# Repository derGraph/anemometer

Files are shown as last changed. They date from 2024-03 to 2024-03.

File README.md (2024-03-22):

# Ultrasonic Anemometer

This project contains the circuit and code for a ultrasonic Anemometer. The anemometer works by 4 ultrasonic Transducers where 2 of them always face each other. 2 Transducers describe one Axis, so with 4 Transducers you can measure x and y Wind components. The circuit only recieves the signal and boosts a Peak-to-Peak Sine Voltage of 50mV to a Square Wave of VCC to 0V. With the microcontroller you have to compare the time difference between the output signal, a signal of 50% Duty Cycle 40kHz and the recieved signal. Then you can calibrate your sensor with 0 wind speed. In my case i measure the Clock Cycles of an ESP8266 to get a pretty precise time.

### Circuit Description


The circuit contains of a LM324 OP-Amp and an LM393 Comperator. With these 2 IC's you can archive processing for 2 Channels. after the signal is coming from the transducer it gets biased with a VCC/2 Voltage to be in a useful working range for the later components. Then the signal is fed through a voltage follower to get a low impedance signal for the next Amplifier stage. The next stage is, as said an inverting Amplifier with a gain of 10. The gain can't be to high to have a functioning amplification. As you can see if you have signal at 40kHz the maximum gain can be 10. 
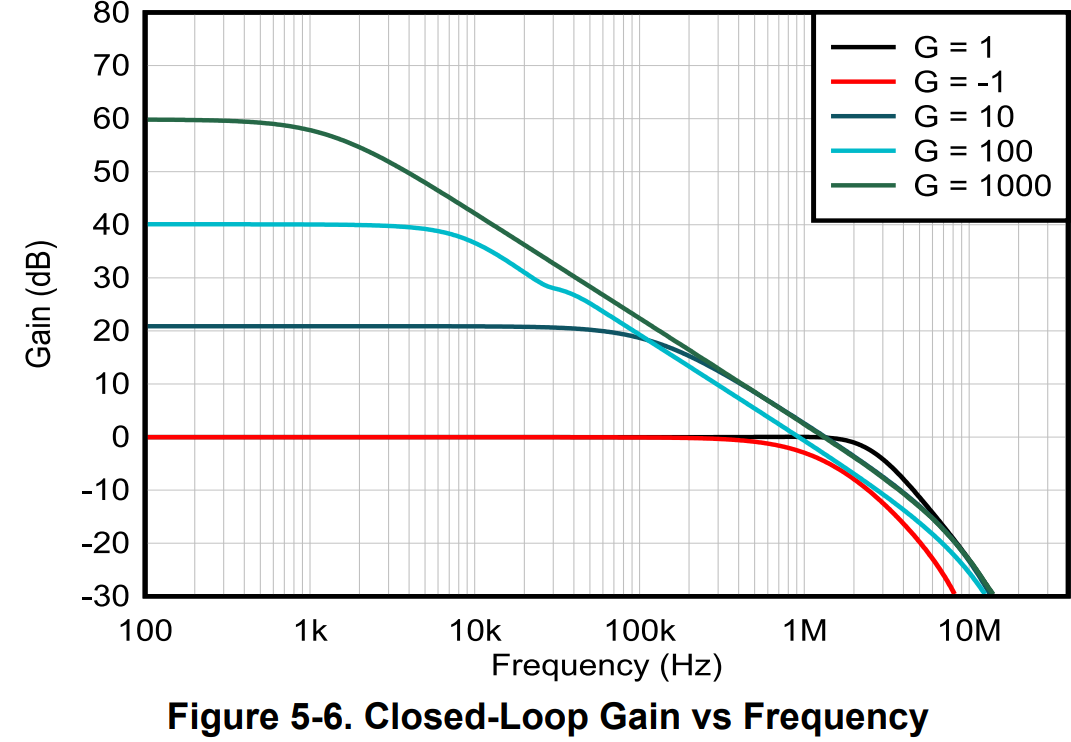
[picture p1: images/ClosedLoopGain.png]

After that the signal is fed into the LM393 Comparator. Keep in mind that to get the comperator to function you have to pull the output up. In the first revision of the board  (Rev 1) there are 2 Footprints of resistors too much (R5, R14) this is fixed with Rev 2.

### Modularity

In the standard configuration of the PCB 2 Channels are set up but if you have a weaker Signal you can cut the S2_EN between 1/2 and solder 2/3. By populating R17 and R18 you can transform your 1 Stage Amplifier in a 3 Stage Amplifier.
If you need an additional Filter you can cut EN_Filter and populate the Bandpass-Filter on the backside of the PCB.

### Full Circuit



The whole circuit contains 2 Channels with the logic to implement the 3 Stage Amplifier included in the lower one. Also there is power supply and connectors to the MCU.

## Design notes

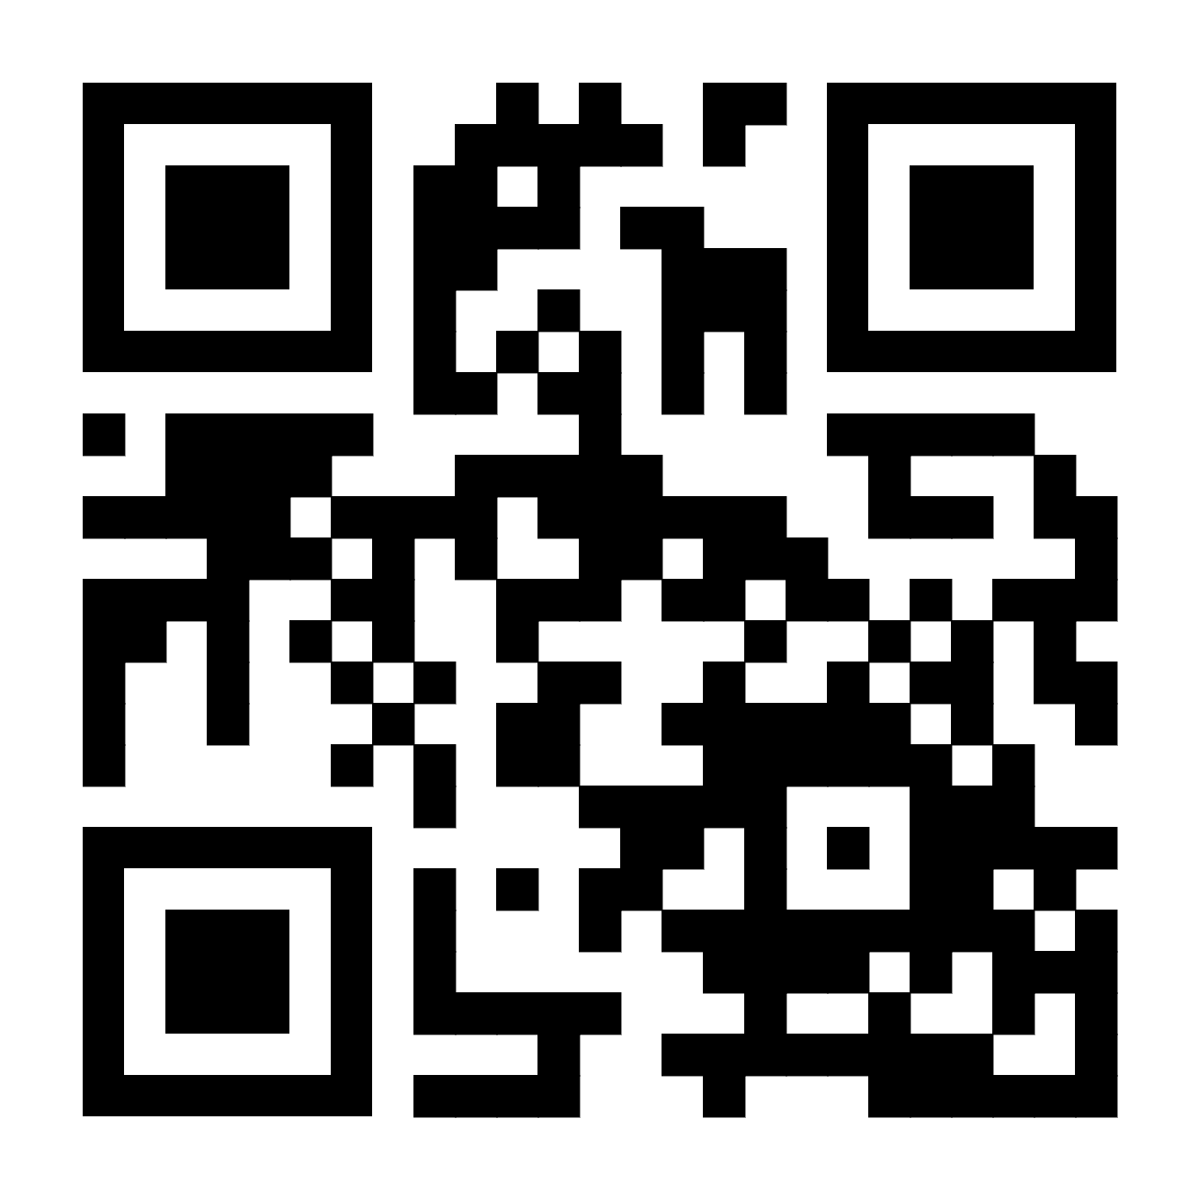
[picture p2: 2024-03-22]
KiCad/GitHubQR.png

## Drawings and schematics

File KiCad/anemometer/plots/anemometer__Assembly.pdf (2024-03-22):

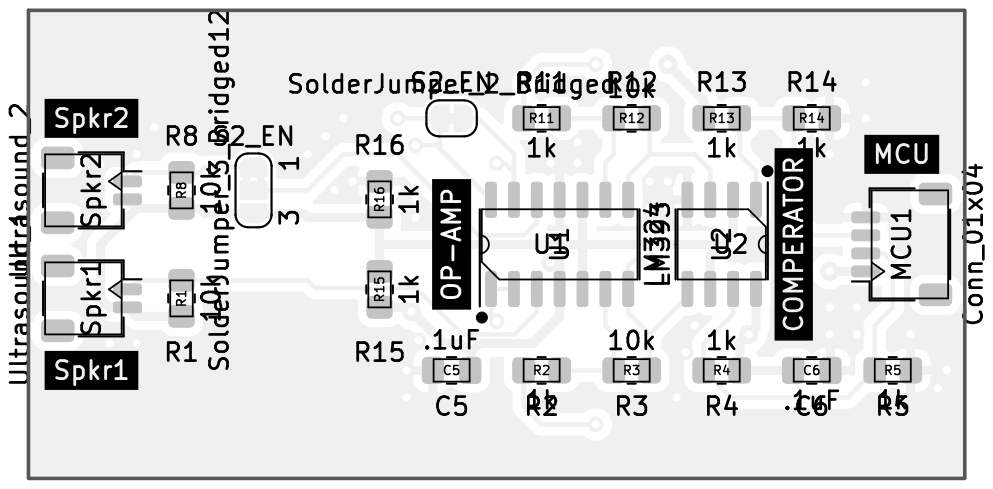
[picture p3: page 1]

Id: 1/1 Title: File: anemometer.kicad_pcb Sheet:

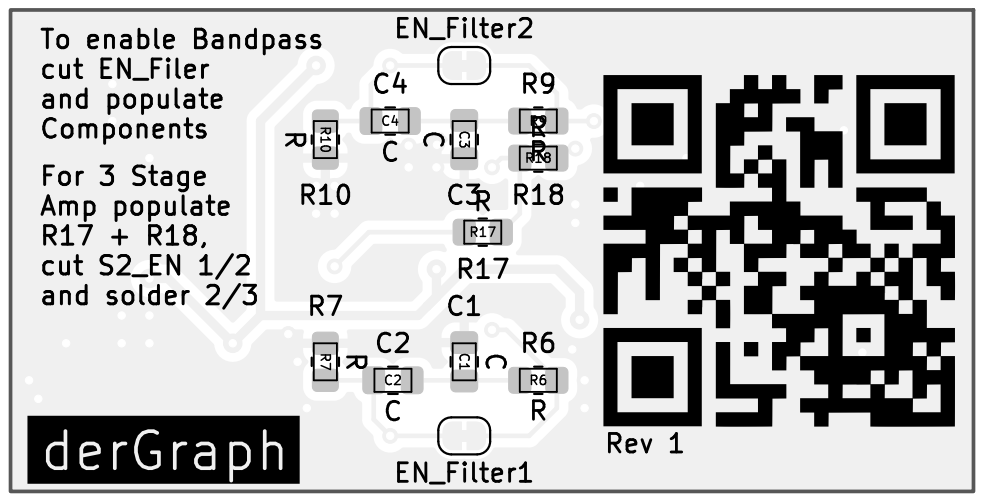
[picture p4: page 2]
D Date: KiCad; E.D.A. kicad; 7.0.5 Size: A4; Rev:; Id: 1/1 Title: File: anemometer.kicad_pcb Sheet:

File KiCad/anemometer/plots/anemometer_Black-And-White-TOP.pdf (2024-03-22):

1 | 2 | 3 | 4 | 5 | 6

A


Id: 1/1 Title: File: anemometer.kicad_pcb Sheet:

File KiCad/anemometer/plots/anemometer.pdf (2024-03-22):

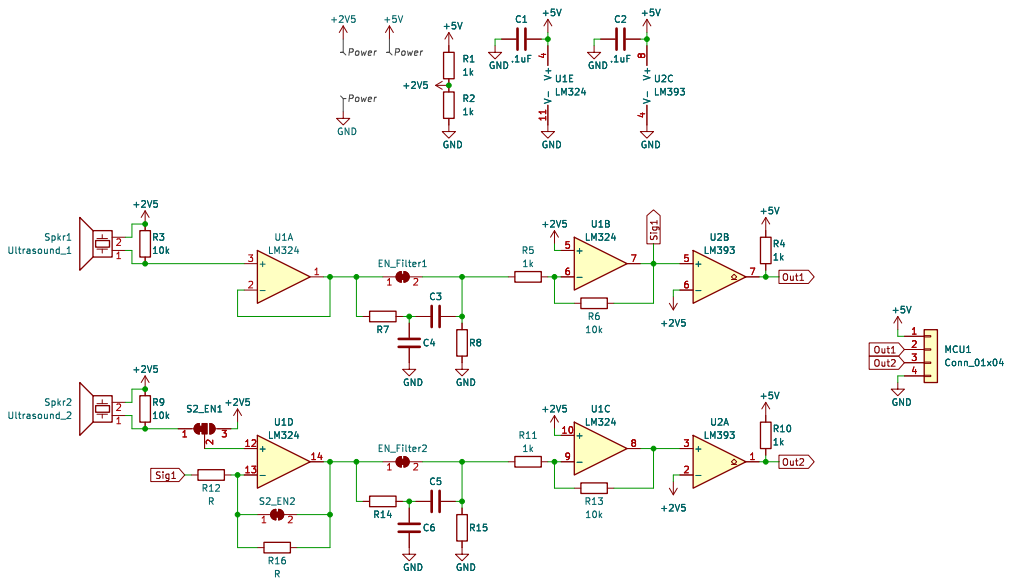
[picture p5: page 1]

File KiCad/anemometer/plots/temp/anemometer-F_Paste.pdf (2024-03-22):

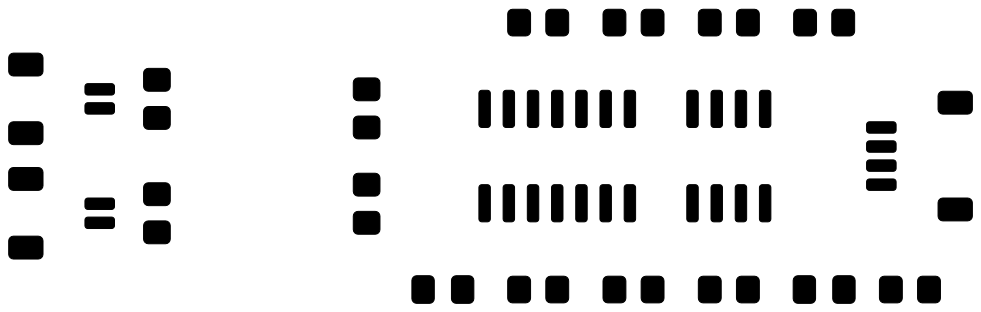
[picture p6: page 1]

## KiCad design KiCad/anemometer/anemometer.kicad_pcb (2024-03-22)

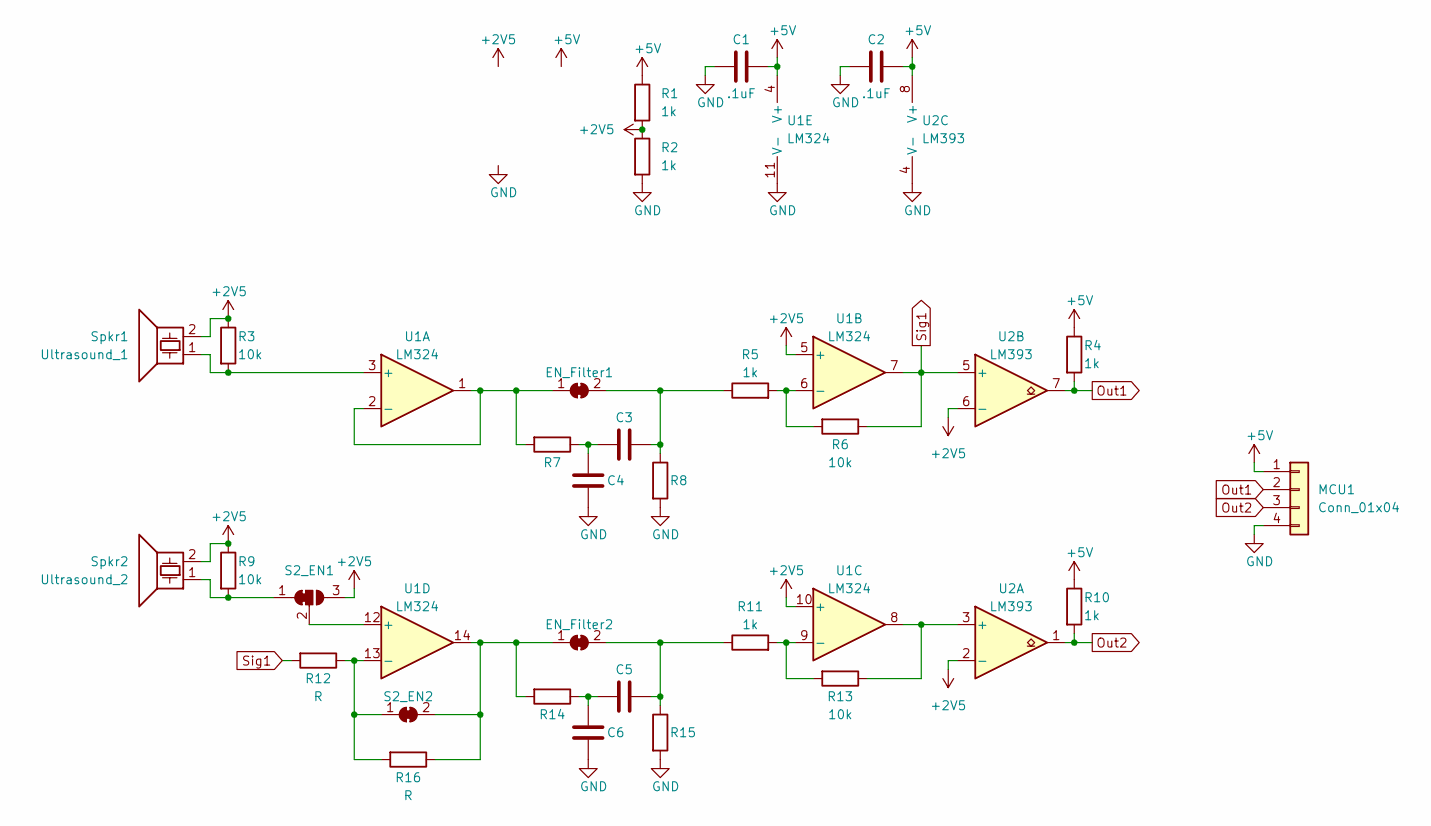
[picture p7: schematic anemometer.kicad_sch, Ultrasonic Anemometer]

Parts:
C1, C2: .1uF; C_0805_2012Metric_Pad1.18x1.45mm_HandSolder
C3, C4, C5, C6: C; C_0805_2012Metric_Pad1.18x1.45mm_HandSolder
EN_Filter1, EN_Filter2: SolderJumper_2_Bridged; SolderJumper-2_P1.3mm_Bridged_RoundedPad1.0x1.5mm
MCU1: Conn_01x04; JST_SH_SM04B-SRSS-TB_1x04-1MP_P1.00mm_Horizontal
R1, R2, R4, R5, R10, R11: 1k; R_0805_2012Metric_Pad1.20x1.40mm_HandSolder
R3, R6, R9, R13: 10k; R_0805_2012Metric_Pad1.20x1.40mm_HandSolder
R7, R8, R12, R14, R15, R16: R; R_0805_2012Metric_Pad1.20x1.40mm_HandSolder
S2_EN1: SolderJumper_3_Bridged12; SolderJumper-3_P1.3mm_Bridged2Bar12_RoundedPad1.0x1.5mm_Num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
S2_EN2: SolderJumper_2_Bridged; SolderJumper-2_P1.3mm_Bridged_RoundedPad1.0x1.5mm
Spkr1: Ultrasound_1; JST_SH_SM02B-SRSS-TB_1x02-1MP_P1.00mm_Horizontal
Spkr2: Ultrasound_2; JST_SH_SM02B-SRSS-TB_1x02-1MP_P1.00mm_Horizontal
U1: LM324; SOIC-14_3.9x8.7mm_P1.27mm
U2: LM393; SOIC-8_3.9x4.9mm_P1.27mm

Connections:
+2V5: R1.2, R2.1, R3.1, R9.1, S2_EN1.3 (B), Spkr1.2, Spkr2.2, U1.5 (+), U1.10 (+), U2.2 (-), U2.6 (-)
+5V: C1.1, C2.1, MCU1.1, R1.1, R4.1, R10.1, U1.4 (V+), U2.8 (V+)
GND: C1.2, C2.2, C4.2, C6.2, MCU1.4, R2.2, R8.2, R15.2, U1.11 (V-), U2.4 (V-)
unnamed: C3.2, C4.1, R7.1
unnamed: C5.2, C6.1, R14.1
unnamed: EN_Filter1.1 (A), R7.2, U1.1, U1.2 (-)
unnamed: C3.1, EN_Filter1.2 (B), R5.1, R8.1
unnamed: EN_Filter2.1 (A), R14.2, R16.1, S2_EN2.2 (B), U1.14
unnamed: C5.1, EN_Filter2.2 (B), R11.1, R15.1
unnamed: R9.2, S2_EN1.1 (A), Spkr2.1
unnamed: S2_EN1.2 (C), U1.12 (+)
unnamed: R12.1, R16.2, S2_EN2.1 (A), U1.13 (-)
unnamed: R3.2, Spkr1.1, U1.3 (+)
unnamed: R5.2, R6.2, U1.6 (-)
unnamed: R11.2, R13.2, U1.9 (-)
unnamed: R13.1, U1.8, U2.3 (+)
Out1: MCU1.2, R4.2, U2.7
Out2: MCU1.3, R10.2, U2.1
Sig1: R6.1, R12.2, U1.7, U2.5 (+)

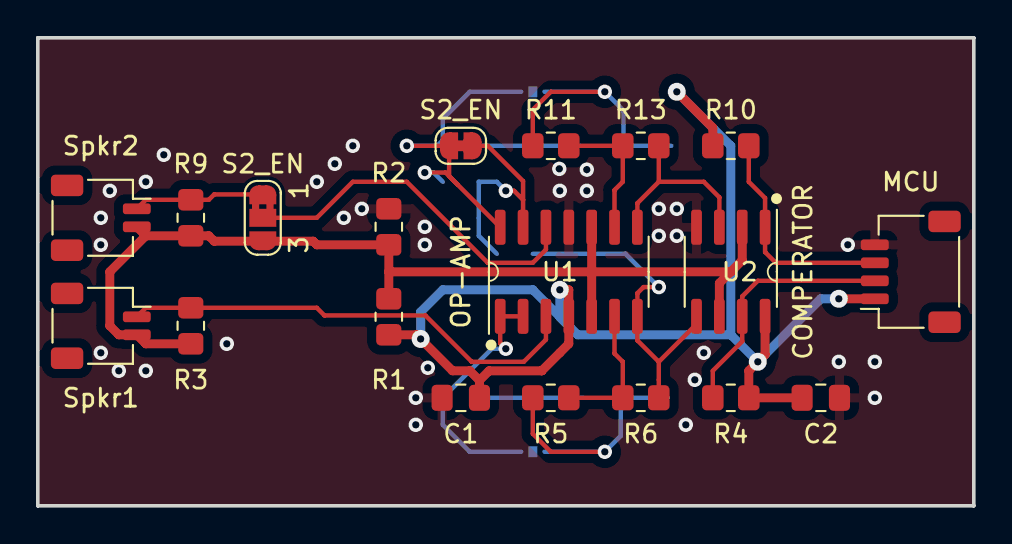
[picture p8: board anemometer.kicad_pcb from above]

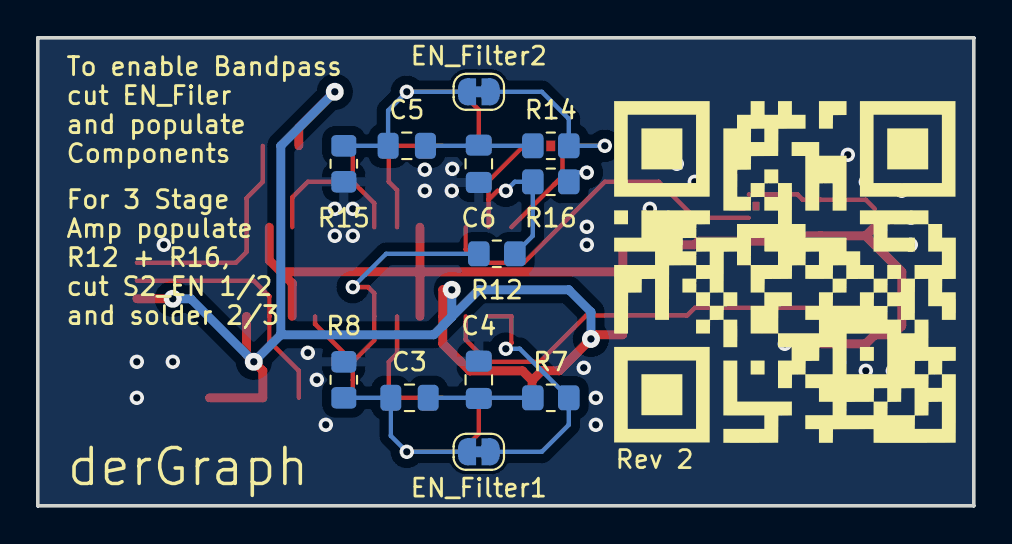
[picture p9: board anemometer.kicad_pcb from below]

Board: 2 copper layers, 52.0 x 26.0 mm, 31 parts (12 on the bottom side), 19 nets.

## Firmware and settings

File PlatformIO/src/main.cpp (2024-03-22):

#include <Arduino.h>

#define outputPin D1 // Output pin for generating 40kHz signal
#define inputPin D2  // Input pin to measure phase shift

long pwmTime = 0; // Time of rising edge of input signal
long phaseShift = 0;     // Phase shift in microseconds
int measurement = 0;


void ICACHE_RAM_ATTR interrupt_pwm() {
  pwmTime = ESP.getCycleCount();
}

void ICACHE_RAM_ATTR interrupt_input() {
  phaseShift += ESP.getCycleCount() - pwmTime;
  measurement++;
}

void setup() {
  Serial.begin(115200); // Initialize serial communication for debugging
  pinMode(inputPin, INPUT_PULLUP);
  
  attachInterrupt(digitalPinToInterrupt(outputPin), interrupt_pwm, RISING);
  attachInterrupt(digitalPinToInterrupt(inputPin), interrupt_input, RISING);
  
  // Configure Timer1 to generate 40kHz square wave
  analogWriteFreq(39643);
  analogWrite(outputPin, 127);
}

void loop() {
  /*detachInterrupt(digitalPinToInterrupt(outputPin));
  detachInterrupt(digitalPinToInterrupt(inputPin));
  if(measurement == 0){
    Serial.println("No Transducer connection");
  }else{
    Serial.println(phaseShift/measurement);
  }
  measurement = 0;
  phaseShift = 0;
  attachInterrupt(digitalPinToInterrupt(outputPin), interrupt_pwm, RISING);
  attachInterrupt(digitalPinToInterrupt(inputPin), interrupt_input, RISING);*/
  delay(100);
}

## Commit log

2024-03-22 initial commit, Rev 1
    [anemometer-B_Cu.gbr, anemometer-B_Mask.gbr, anemometer-B_Silks.gbr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]
2024-03-22 Board Rev 2
    [anemometer-B_Cu.gbr, anemometer-B_Mask.gbr, anemometer-B_Silks.gbr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]
